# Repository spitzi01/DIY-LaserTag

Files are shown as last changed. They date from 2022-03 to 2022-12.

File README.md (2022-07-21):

# ESP32-LaserTag
Easy Open Source LaserTag System
### Überblick
Ziel dieses Projektes war der Bau eines einfachen LaserTag-Systems. Es sollte schnell und mit wenig Hardware an beliebigen Orten aufbaubar sein und  und über ein Handy gesteuert werden können.

Weitere Features sind:

- Soundausgabe für Schuss, Treffer und Nachladen (insgesamt 5 Verschiedene)
- Display in jedem Tagger
- lange Akkulaufzeit des gesamten Systems
- 3 Spielmodi
- Taschenlampe
- rote Laserdiode für Schuss-Simulation
- 5 in den Tagger integriete Infrarot-Empfänger
    
Das LaserTag-System besteht aus zwei elementaren Bestandteilen. Die Basisstation dient als Verbindungsglied zwischen den Taggern, der einzelnen Spieler, und einer HTTP-Website, welche der Konfiguration und Auswertung dient. Der Datenaustausch mit den Spielern erfolgt drahtlos mit Hilfe des EspNow-Protokolls der ESP32 S2 Mikrocontroller. Zum Spielen sind zwischen 2 und 10 Tagger notwendig. Für den Capture the Flag Spielmodus werden zusätzlich noch Flags benötigt, die die Basis und Spawnpunkt eines Team markieren.

### Basisstation
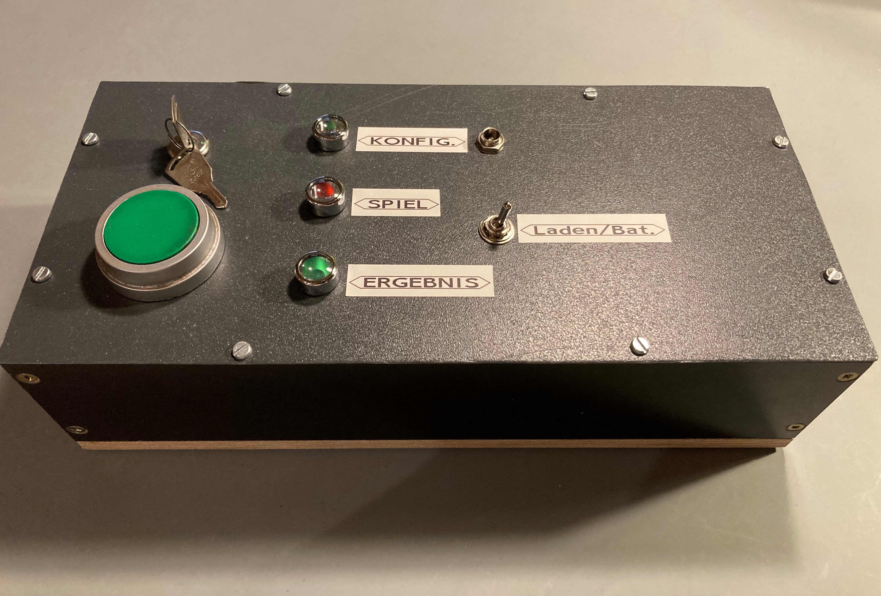
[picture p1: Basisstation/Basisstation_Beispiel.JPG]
Basisstation

Nach dem Einschalten der Basisstation wird ein WLAN-Netzwerk erzeugt und die Konfigurationswebsite gehostet. Wenn man sich hier mit einem Smartphone einloggt, kann man die Anzahl der Spieler, Dauer des Spiels, Modus, Namen der Spieler und Teamzugehörigkeit einstellen. Die maximal 10 Spieler können auf 6 Teams verteilt werden. Vor dem Starten des Spiels mit dem Start-Taster müssen unbedingt alle Tagger, die verwendet werden sollen, eingeschaltet werden, damit diese von der Basisstation ihre Informationen erhalten können. Nach Ablauf der Spieldauer übermitteln die Tagger automatisch die Spielstände an die Basisstation und schalten sich ab. Die Basisstation berechnet die Ergebnisse und hostet diese in Form einer Website. Das hat den Vorteil, dass sich theoretisch mehrere Spieler die Ergebnisse auf ihren Smartphones anschauen können.

### Tagger
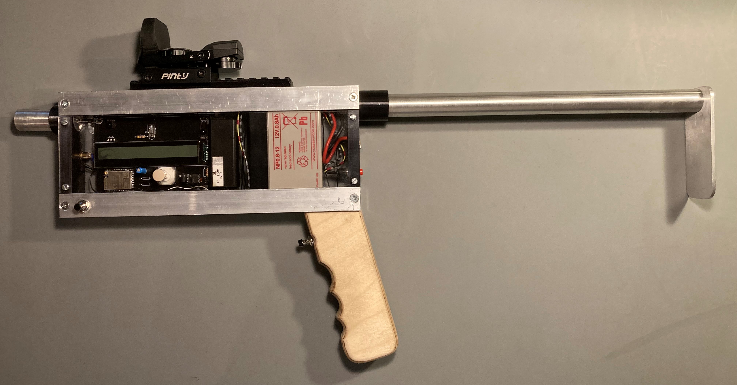
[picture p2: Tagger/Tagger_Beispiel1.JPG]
Tagger1

Bei einem Testsystem wurde festgestellt, dass es dem Spieler nicht möglich sein darf, seinen Tagger aus Versehen auszuschalten. Deshalb wird die Schaltung durch einen Taster aktiviert und nur durch den Mikrocontroller wieder deaktiviert. Außerdem soll der Spieler immer beide Hände am Tagger haben. So soll verhindert werden, dass man mit einer Hand Sensoren abdecken könnte. Dies wird durch einen Taster in Reihe zum eigentlichen Abzug realisiert. Gleichzeitig schaltet dieser auch die Taschenlampe an. In meinem Fall dient ein kleiner 12V Bleiakku aus einer Brandmeldezentrale als Energieversorgung. Mit Hilfe des Step Down Converters wird eine hohe Effizienz und Akkulaufzeit erreicht. Das Display hat 20 alphanumerische Stellen, welche die Namen der Spieler und die Anzahl der Leben anzeigen. Eine Hintergrundbeleuchtung ist nicht vorhanden, da diese zu viel Strom benötigen würde. Deshalb dient die RGB-LED für die Teamzugehörigkeit als Beleuchtung.

Tagger2

Der Schuss wird durch eine Laserdiode visualisiert. Die eigentliche Information findet durch eine IR-Übertragung ihren Weg zu anderen Spielern. Bei Tests in der Nacht konnte eine Reichweite von bis zu 60 Meter erzielt werden. Der kurze Alu-Lauf dient als Reflektor für die Infrarot-LED und auch als Kühlkörper, da bei aktiviertem Schnellfeuermodus die LED sehr belastet wird.

Die verfügbaren Spielmodi sind:

- Standard (Spielen in Teams oder Einzeln, Reaktivierung nach ca. 20 Sekunden)
- Battle Royal (Spielen in Teams oder Einzeln, Leben werden bei Treffer weniger, kein Treffer in gewisser Zeit fügt ein Leben hinzu, lange Reaktivierungszeit ca. 2 Minuten)
- Capture the Flag (2 Teams rot & blau, Flags markieren Basis oder Spawnpunkt des jeweiligen Teams, Reaktivierung nur im Bereich des eigenen Spawnpunkts, Punkte bei Aufenthalt in gegnerischen Basis)

### Flag
Ein Flag sendet in regelmäßigen Abständen einen Code der von den Taggern empfangen wird. Bereich, in dem das Signal empfangbar ist, beträgt in etwa 5-8 Meter im Radius. Diese Strecke ergibt sich durch den Einsatz von ESP32 S2 Mikrocontroller ohne integriete Antenne in den Taggern.

### Verbesserungsmöglichkeiten

- Reichweite bei starkem Sonnenschein eingeschränkt
- Mikrocontroller überträgt kurzes Störgeräusch über I2S nach Ende einer Soundausgabe (Software Problem)
- Skalierbarkeit (mehr als 10 Spieler)

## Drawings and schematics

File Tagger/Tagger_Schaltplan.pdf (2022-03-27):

GND¹⁰k +3V³ ⁺³V³ | +3V³ | 31DQ⁰⁶
3,3 | 10k 10k

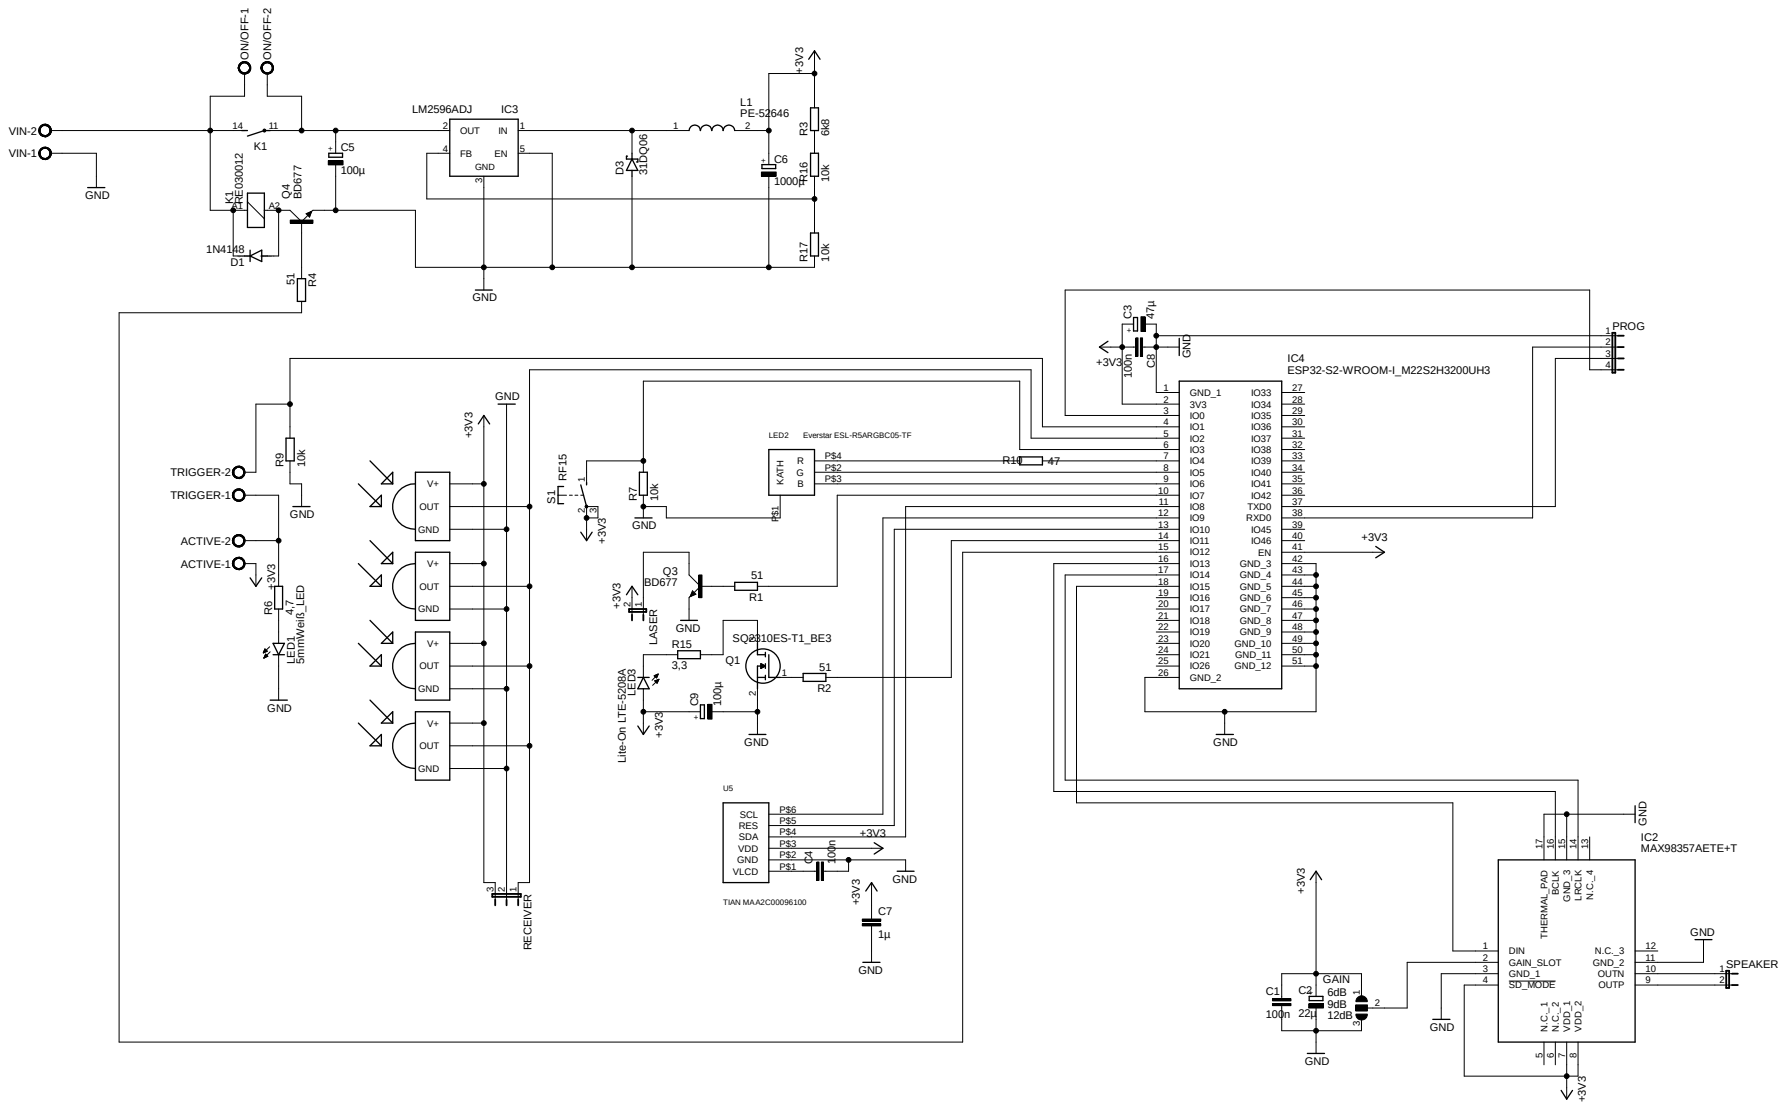
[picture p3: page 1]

GAIN ³²¹ RECEIVER Q⁴

IO10 13
IO11 14

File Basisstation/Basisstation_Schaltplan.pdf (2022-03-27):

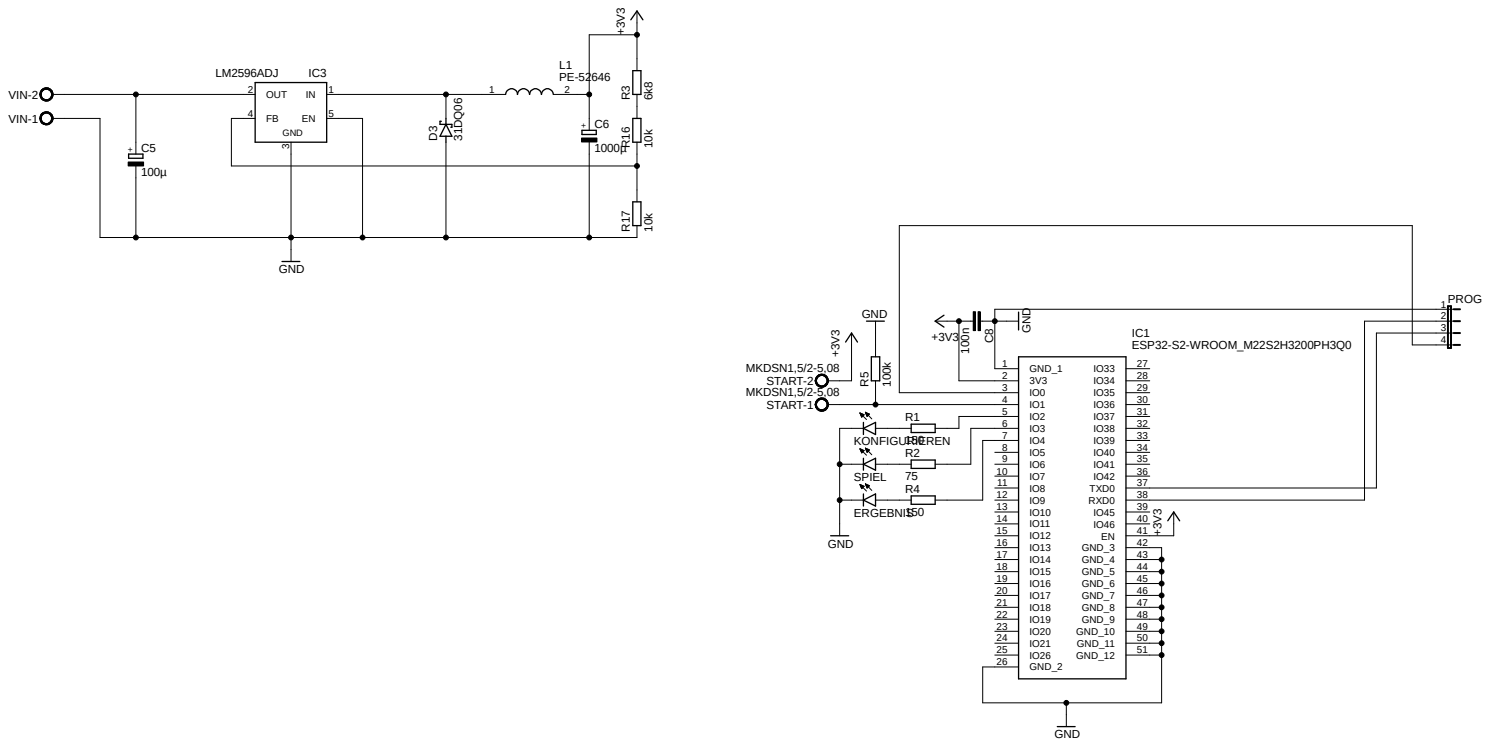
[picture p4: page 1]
GND; GND 100n; +3V3 ⁺³V³ 31DQ⁰⁶; PE-52646 LM2596ADJ; ESP32-S2-WROOM_M22S2H3200PH3Q0 +3V³; MKDSN1,5/2-5,08; MKDSN1,5/2-5,08⁺³V³; 150 ¹⁰⁰k; R¹⁶ R¹⁷; 1 OUT; 5 IC3 VIN-1 VIN-2; GND_1; 9 IO7 10 IO8 11 IO9 12 IO10 13 IO11 14 IO12 15 IO13 16 IO14 17 IO15 18 IO16 19 IO17 20 IO18 21 IO19 22 IO20 23 IO21 24 IO26 25 GND_2 26; TXD0; RXD0; GND_3; GND_4; GND_5; GND_6; GND_7; GND_8; GND_9; GND_10; GND_11; GND_12; 1234PROG; START-1; START-2; ERGEBNIS; SPIEL; KONFIGURIEREN ⁺

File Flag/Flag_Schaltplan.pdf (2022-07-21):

# D2 ¹²³ON/OFF

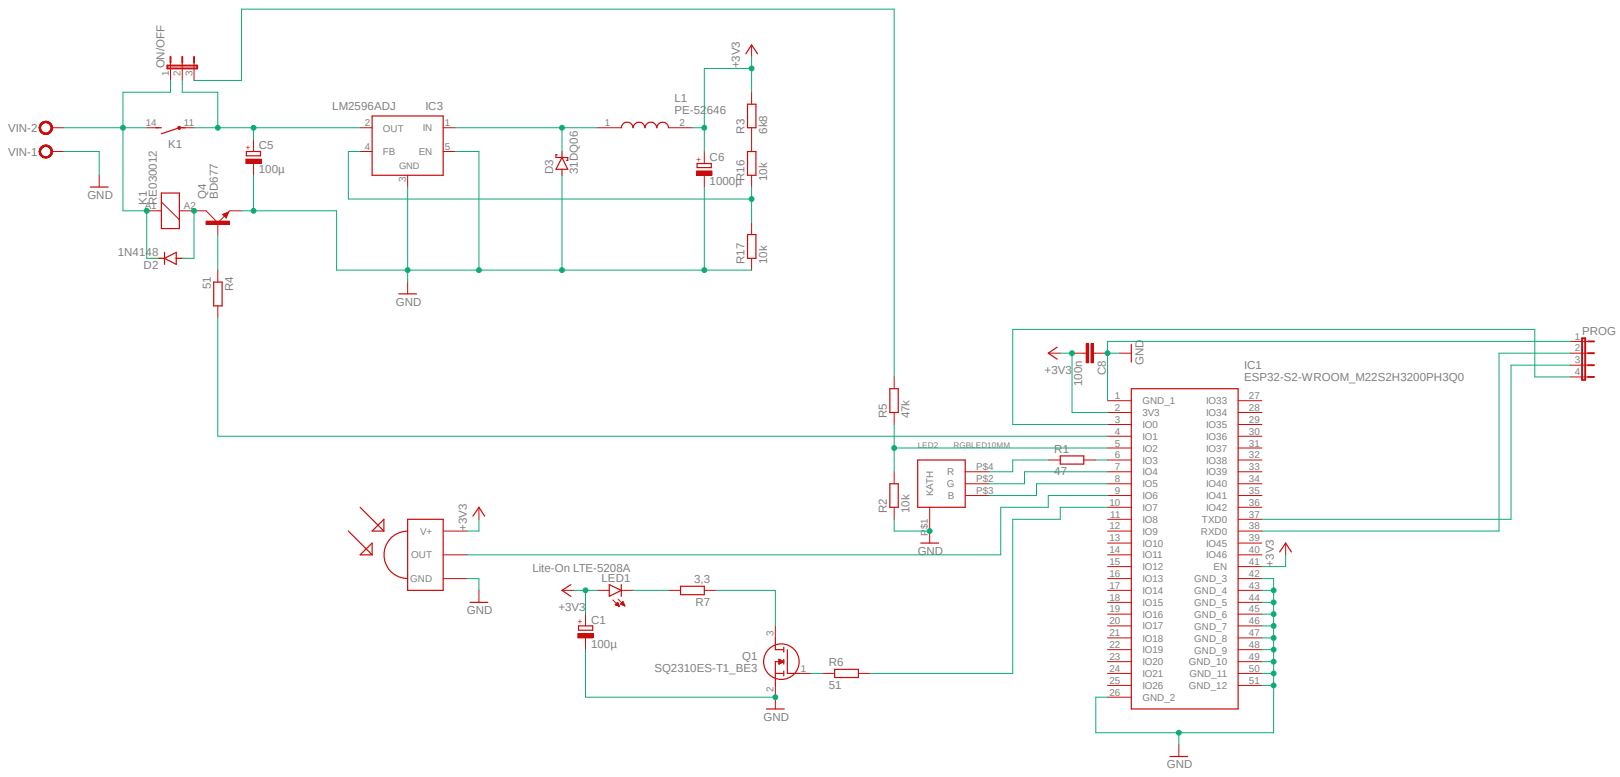
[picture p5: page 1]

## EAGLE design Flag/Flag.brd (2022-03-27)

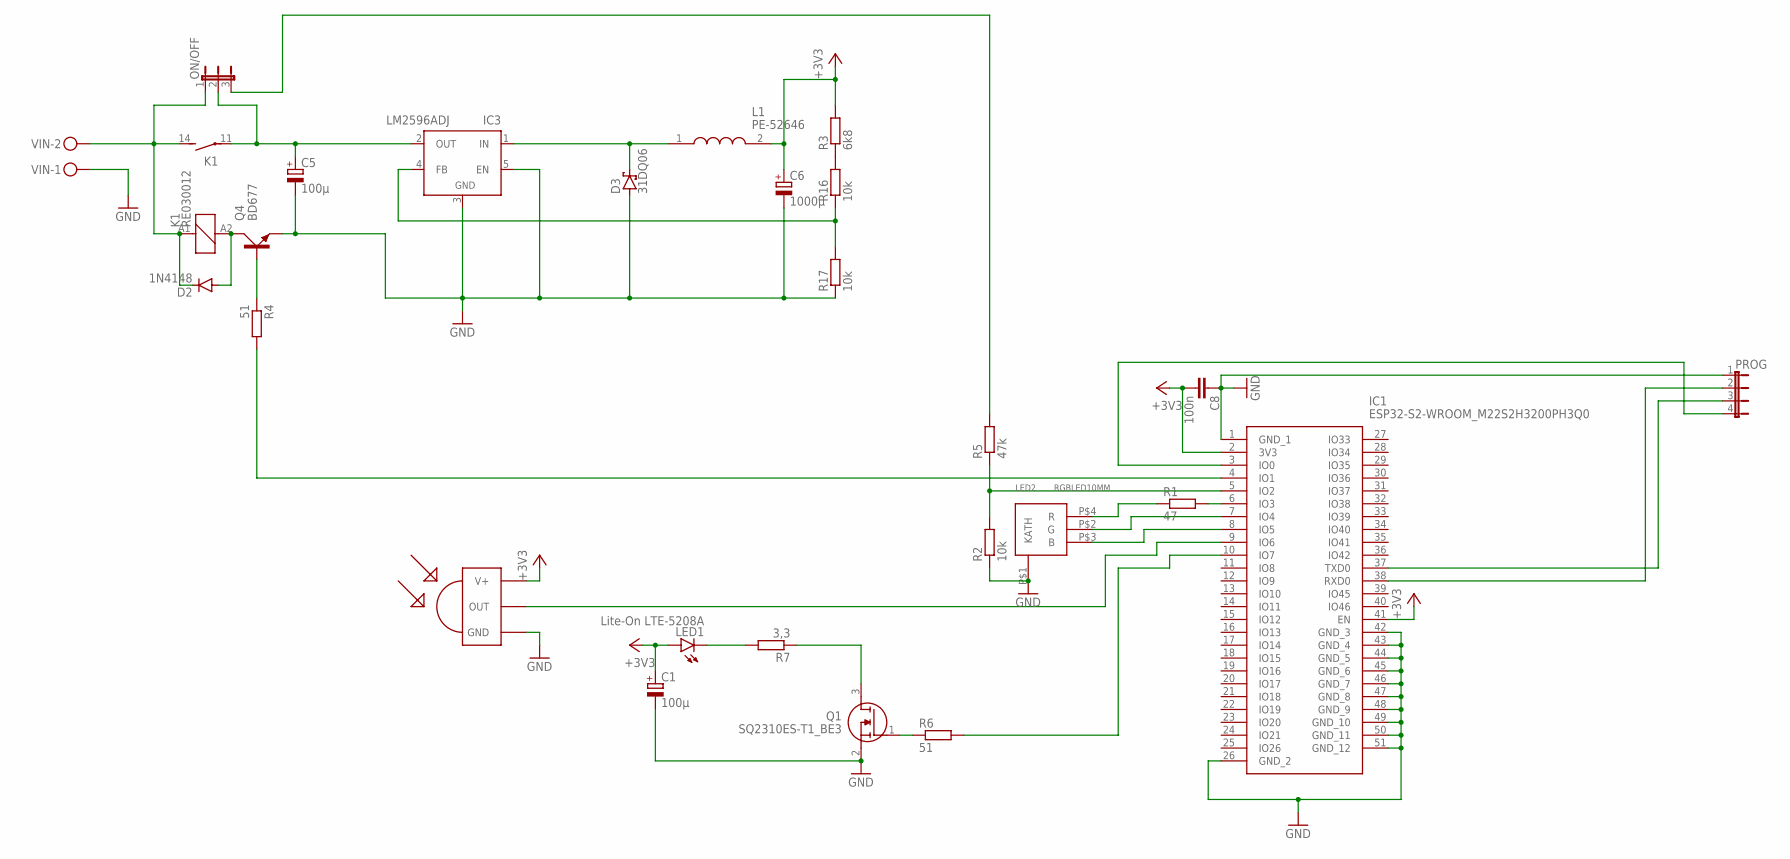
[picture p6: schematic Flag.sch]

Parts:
C1: 100µ; E3,5-8
C5: 100µ; E5-10,5
C6: 1000µ; E3,5-8
C8: 100n; C050-025X075
D2: 1N4148; SOD80C
D3: 31DQ06; C4111-15
IC1: ESP32-S2-WROOM_M22S2H3200PH3Q0; ESP32S2WROOMM22S2H3200PH3Q0
IC3: LM2596ADJ; TO220-52
K1: RE030012; RE-SCHRACK
L1: PE-52646; PE52646
LED1: Lite-On LTE-5208A; LED5MM
LED2: RGBLED10MM
ON/OFF: JP2E; JP2
PROG: JP4E; JP4
Q1: SQ2310ES-T1_BE3; SOT95P237X112-3N
Q4: BD677; TO126AV
R1: 47; 0207/10
R2: 10k; 0207/10
R3: 6k8; R1206
R4, R6: 51; R1206
R5: 47k; 0207/10
R7: 3,3; 0207/10
R16, R17: 10k; R1206
U1: TSOP33338; TSOP18XX
VIN: MKDSN1,5/2-5,08

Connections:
+3V3: C1.+, C6.+, C8.2, IC1.2 (3V3), IC1.41 (EN), L1.2, LED1.A, R3.2, U1.VCC (V+)
GND: C1.-, C5.-, C6.-, C8.1, D3.A, IC1.1 (GND_1), IC1.26 (GND_2), IC1.42 (GND_3), IC1.43 (GND_4), IC1.44 (GND_5), IC1.45 (GND_6), IC1.46 (GND_7), IC1.47 (GND_8), IC1.48 (GND_9), IC1.49 (GND_10), IC1.50 (GND_11), IC1.51 (GND_12), IC3.3 (GND), IC3.5 (EN), LED2.P$1 (KATH), PROG.1, Q1.2 (S), Q4.E, R2.1, R17.1, U1.GND, VIN.1
unnamed: C5.+, IC3.2 (OUT), K1.11, ON/OFF.2
unnamed: IC1.4 (IO1), R4.2
unnamed: D2.C, K1.14 (S), K1.A1 (1), ON/OFF.1, VIN.2
unnamed: D2.A, K1.A2 (2), Q4.C
unnamed: LED2.P$4 (R), R1.1
unnamed: IC1.7 (IO4), LED2.P$2 (G)
unnamed: IC1.8 (IO5), LED2.P$3 (B)
unnamed: D3.C, IC3.1 (IN), L1.1
unnamed: IC3.4 (FB), R16.1, R17.2
unnamed: IC1.6 (IO3), R1.2
unnamed: IC1.5 (IO2), R2.2, R5.1
unnamed: IC1.9 (IO6), U1.OUT
unnamed: ON/OFF.3, R5.2
unnamed: IC1.10 (IO7), R6.2
unnamed: Q1.1 (G), R6.1
unnamed: LED1.K (C), R7.2
unnamed: Q1.3 (D), R7.1
unnamed: Q4.B, R4.1
unnamed: IC1.3 (IO0), PROG.4
unnamed: IC1.37 (TXD0), PROG.3
unnamed: IC1.38 (RXD0), PROG.2
unnamed: R3.1, R16.2

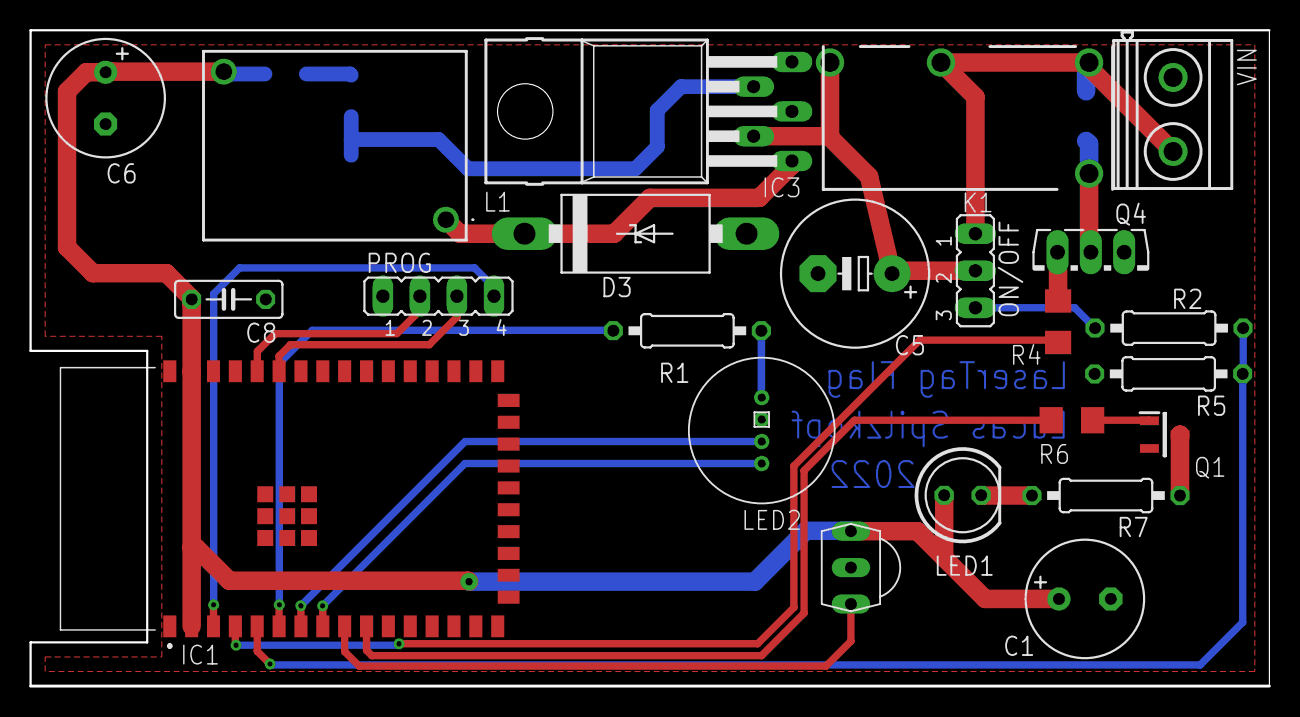
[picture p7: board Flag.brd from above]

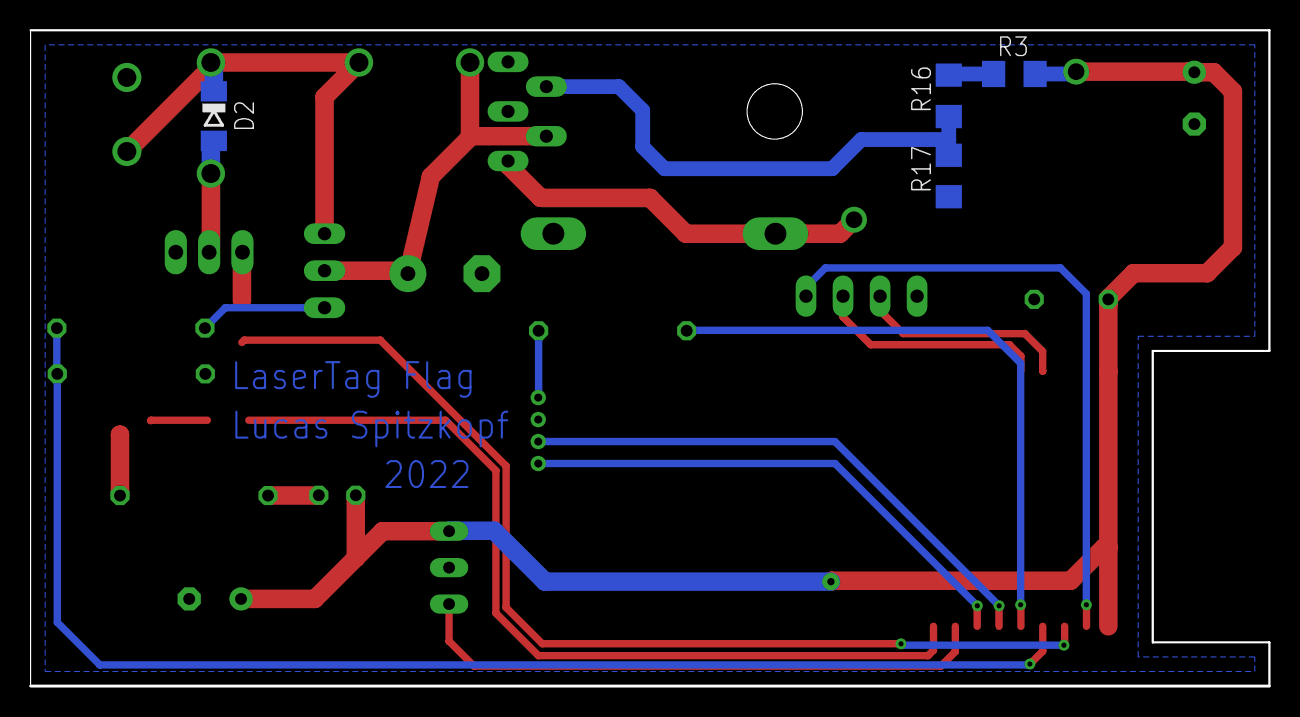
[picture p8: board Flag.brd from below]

Board: 2 copper layers, 85.0 x 45.0 mm, 27 parts (4 on the bottom side), 24 nets.

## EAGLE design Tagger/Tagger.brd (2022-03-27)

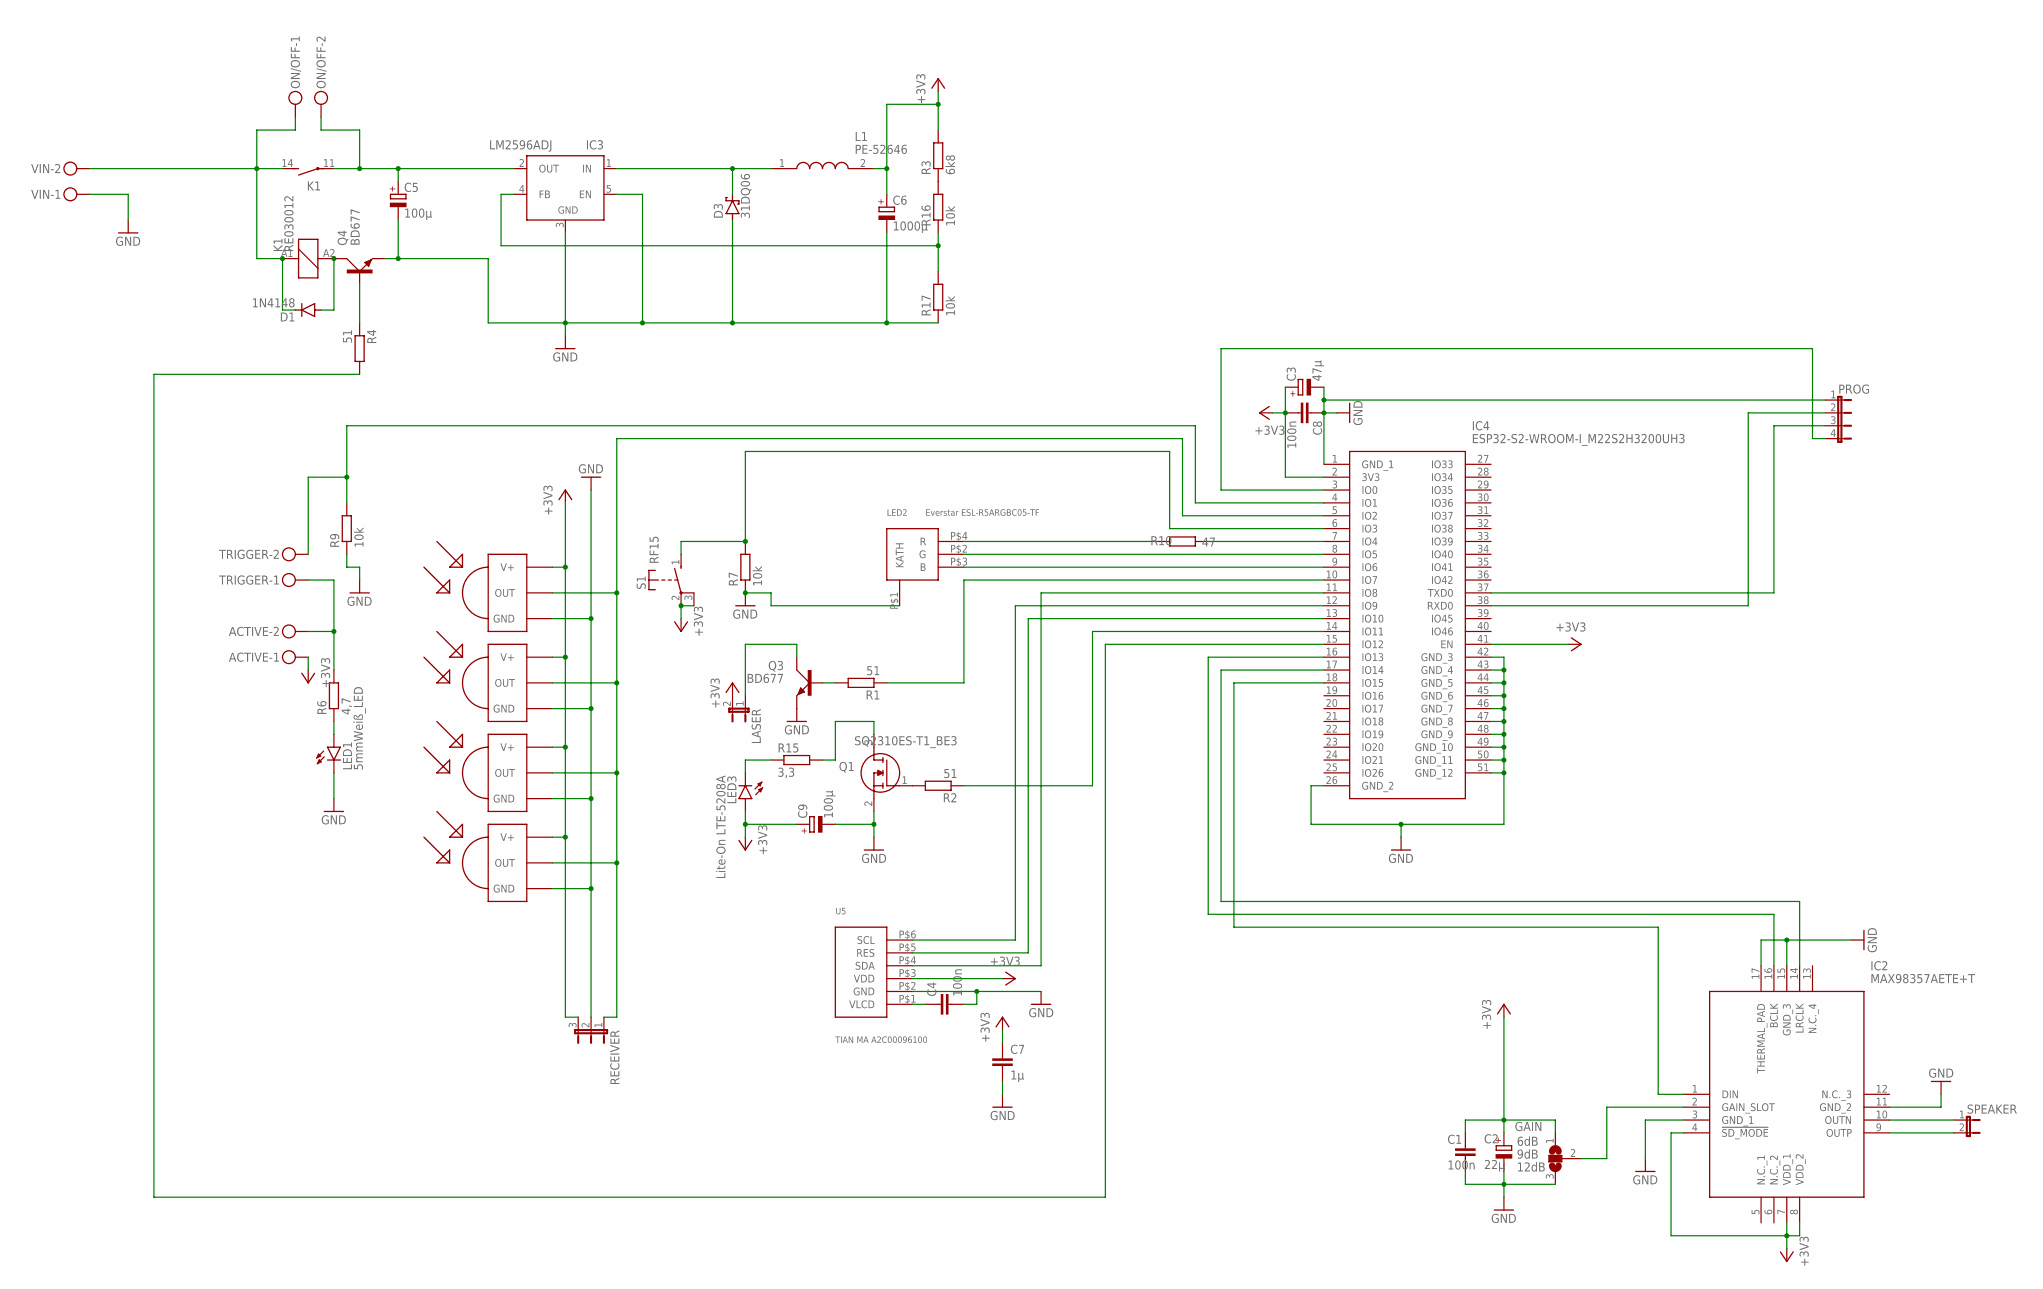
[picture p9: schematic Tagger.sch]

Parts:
ACTIVE: MKDSN1,5/2-5,08
C1, C4, C8: 100n; C1206
C2: 22µ; E2-5
C3: 47µ; E2-5
C5: 100µ; E2,5-6E
C6: 1000µ; E5-10,5
C7: 1µ; C0805
C9: 100µ; E2,5-6
D1: 1N4148; SOD80C
D3: 31DQ06; C4111-15
GAIN: SJ2WW; SJ_2W
IC2: MAX98357AETE+T; QFN50P300X300X80-17N
IC3: LM2596ADJ; TO220-52
IC4: ESP32-S2-WROOM-I_M22S2H3200UH3; ESP32S2WROOMIM22S2H3200UH3Q0
K1: RE030012; RE-SCHRACK
L1: PE-52646; PE52646
LASER: JP1E; JP1
LED1: 5mmWeiß_LED; LED5MM
LED2: Everstar ESL-R5ARGBC05-TF; RGBLED5MM
LED3: Lite-On LTE-5208A; LED5MM
ON/OFF: MKDSN1,5/2-5,08
PROG: JP4E; JP4
Q1: SQ2310ES-T1_BE3; SOT95P237X112-3N
Q3, Q4: BD677; TO126AV
R1, R2, R4: 51; R1206
R3: 6k8; R1206
R6: 4,7; 0207/10
R7, R9, R16, R17: 10k; R1206
R10: 47; 0207/10
R15: 3,3; 0207/10
RECEIVER: JP2E; JP2
S1: RF15
SPEAKER: JP1E; JP1
TRIGGER: MKDSN1,5/2-5,08
U1, U2, U3, U4: TSOP33338; TSOP18XX
U5: TIAN MA A2C00096100; LCD_DISPLAY
VIN: MKDSN1,5/2-5,08

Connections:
+3V3: ACTIVE.1, C1.1, C2.+, C3.+, C6.+, C7.1, C8.2, C9.+, GAIN.1, IC2.4 (!SD_MODE), IC2.7 (VDD_1), IC2.8 (VDD_2), IC4.2 (3V3), IC4.41 (EN), L1.2, LASER.2, LED3.A, R3.2, RECEIVER.3, S1.2, S1.3, U1.VCC (V+), U2.VCC (V+), U3.VCC (V+), U4.VCC (V+), U5.P$3 (VDD)
GND: C1.2, C2.-, C3.-, C4.2, C5.-, C6.-, C7.2, C8.1, C9.-, D3.A, GAIN.3, IC2.3 (GND_1), IC2.11 (GND_2), IC2.15 (GND_3), IC2.17 (THERMAL_PAD), IC3.3 (GND), IC3.5 (EN), IC4.1 (GND_1), IC4.26 (GND_2), IC4.42 (GND_3), IC4.43 (GND_4), IC4.44 (GND_5), IC4.45 (GND_6), IC4.46 (GND_7), IC4.47 (GND_8), IC4.48 (GND_9), IC4.49 (GND_10), IC4.50 (GND_11), IC4.51 (GND_12), LED1.K (C), LED2.P$1 (KATH), PROG.1, Q1.2 (S), Q3.E, Q4.E, R7.1, R9.1, R17.1, RECEIVER.2, U1.GND, U2.GND, U3.GND, U4.GND, U5.P$2 (GND), VIN.1
unnamed: C5.+, IC3.2 (OUT), K1.11, ON/OFF.2
unnamed: GAIN.2, IC2.2 (GAIN_SLOT)
unnamed: D1.C, K1.14 (S), K1.A1 (1), ON/OFF.1, VIN.2
unnamed: D1.A, K1.A2 (2), Q4.C
unnamed: IC4.7 (IO4), R10.2
unnamed: IC2.10 (OUTN), SPEAKER.1
unnamed: IC2.1 (DIN), IC4.18 (IO15)
unnamed: C4.1, U5.P$1 (VLCD)
unnamed: D3.C, IC3.1 (IN), L1.1
unnamed: IC3.4 (FB), R16.1, R17.2
unnamed: IC2.14 (LRCLK), IC4.17 (IO14)
unnamed: IC4.14 (IO11), R2.1
unnamed: LED3.K (C), R15.1
unnamed: LASER.1, Q3.C
unnamed: LED1.A, R6.1
unnamed: IC4.11 (IO8), U5.P$4 (SDA)
unnamed: Q1.3 (D), R15.2
unnamed: IC4.6 (IO3), R7.2, S1.1 (S)
unnamed: Q4.B, R4.1
unnamed: LED2.P$4 (R), R10.1
unnamed: IC4.8 (IO5), LED2.P$2 (G)
unnamed: IC4.9 (IO6), LED2.P$3 (B)
unnamed: IC2.16 (BCLK), IC4.16 (IO13)
unnamed: IC4.4 (IO1), R9.2, TRIGGER.2
unnamed: IC4.10 (IO7), R1.1
unnamed: Q3.B, R1.2
unnamed: IC4.13 (IO10), U5.P$5 (RES)
unnamed: IC4.12 (IO9), U5.P$6 (SCL)
unnamed: IC2.9 (OUTP), SPEAKER.2
unnamed: IC4.3 (IO0), PROG.4
unnamed: Q1.1 (G), R2.2
unnamed: IC4.5 (IO2), RECEIVER.1, U1.OUT, U2.OUT, U3.OUT, U4.OUT
unnamed: IC4.37 (TXD0), PROG.3
unnamed: IC4.38 (RXD0), PROG.2
unnamed: ACTIVE.2, R6.2, TRIGGER.1
unnamed: R3.1, R16.2
unnamed: IC4.15 (IO12), R4.2

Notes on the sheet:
12dB
9dB
6dB

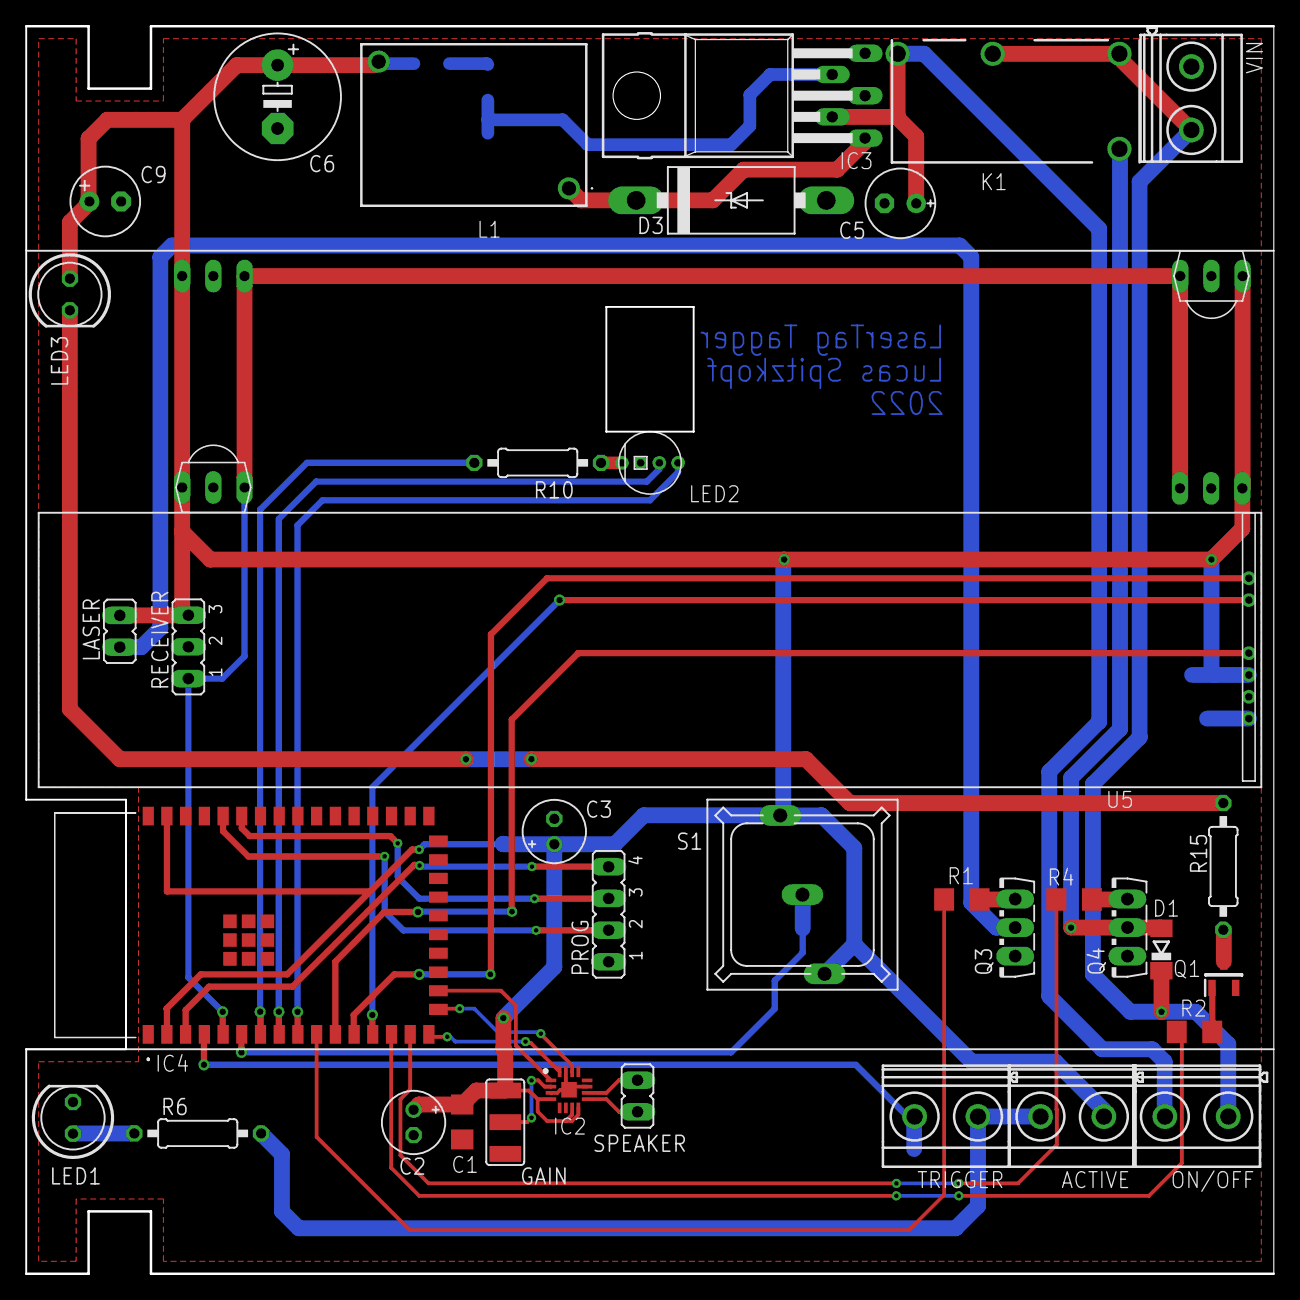
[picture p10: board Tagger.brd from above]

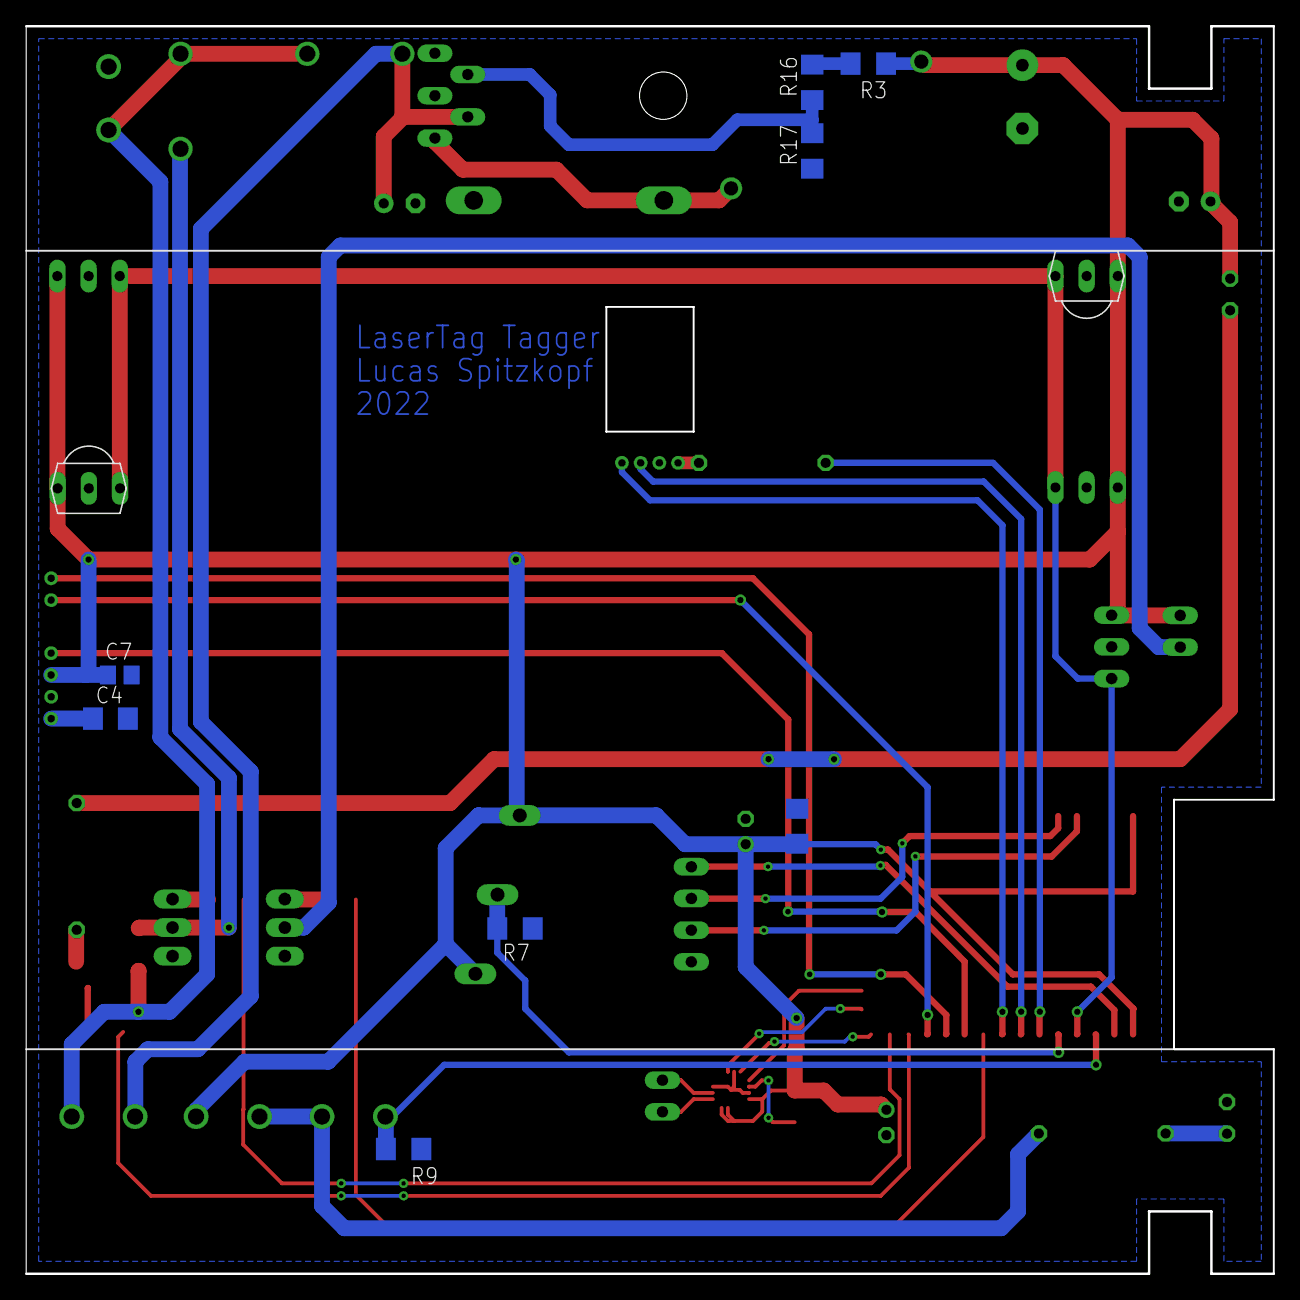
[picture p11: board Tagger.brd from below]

Board: 2 copper layers, 100.0 x 100.0 mm, 48 parts (10 on the bottom side), 39 nets.

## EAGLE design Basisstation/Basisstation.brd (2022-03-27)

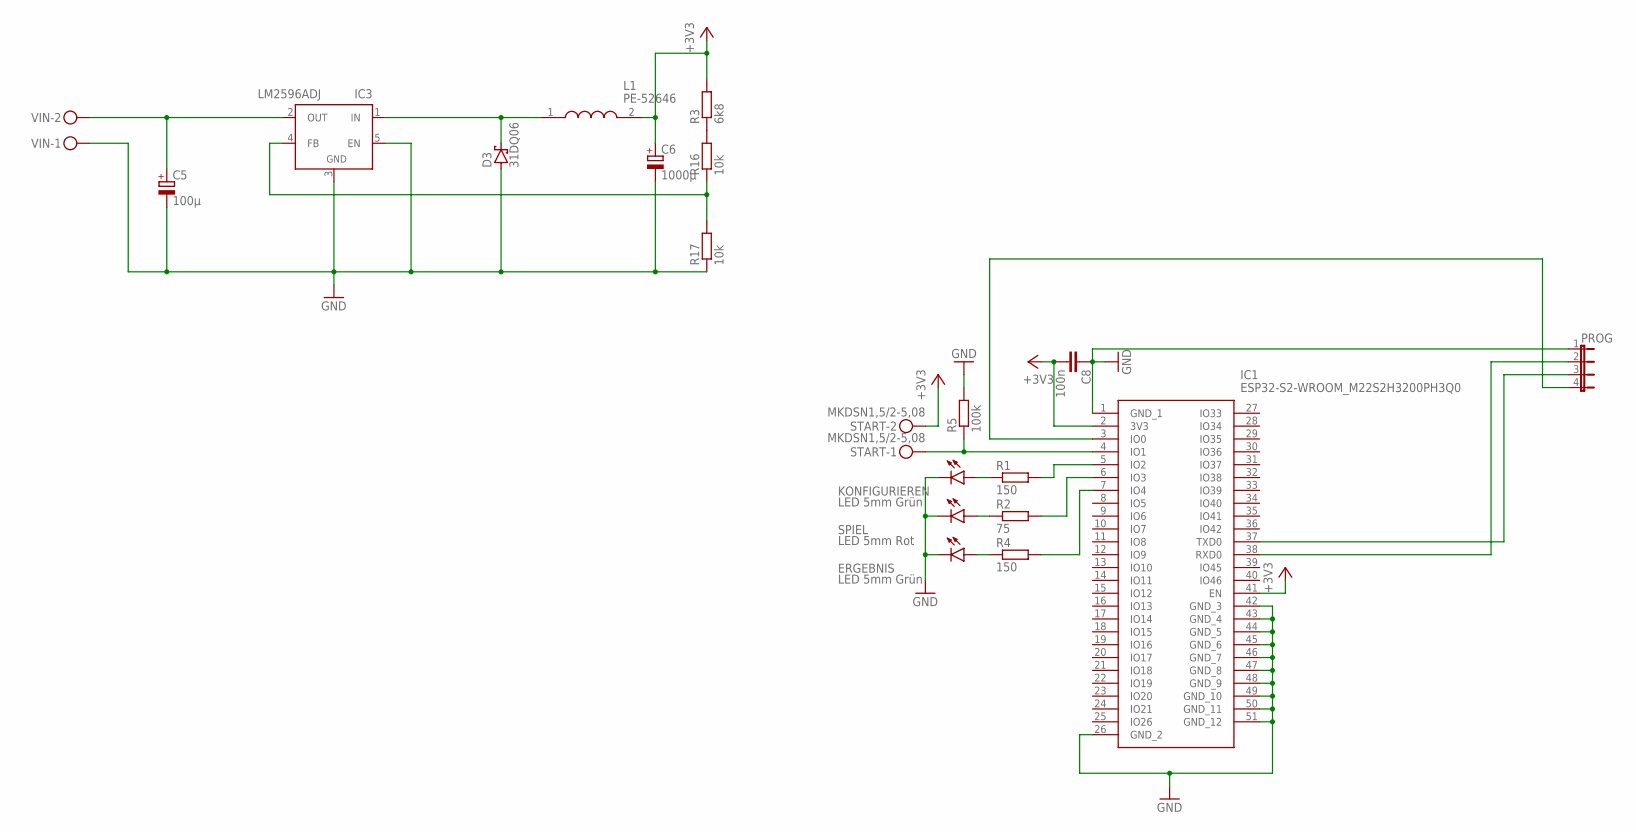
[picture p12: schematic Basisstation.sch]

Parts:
C5: 100µ; E5-10,5
C6: 1000µ; E3,5-8
C8: 100n; C050-025X075
D3: 31DQ06; C4111-15
ERGEBNIS: LED 5mm Grün; LED5MM
IC1: ESP32-S2-WROOM_M22S2H3200PH3Q0; ESP32S2WROOMM22S2H3200PH3Q0
IC3: LM2596ADJ; TO220-52
KONFIGURIEREN: LED 5mm Grün; LED5MM
L1: PE-52646; PE52646
PROG: JP4E; JP4
R1, R4: 150; 0207/10
R2: 75; 0207/10
R3: 6k8; R1206
R5: 100k; 0207/10
R16, R17: 10k; R1206
SPIEL: LED 5mm Rot; LED5MM
START: MKDSN1,5/2-5,08
VIN: MKDSN1,5/2-5,08

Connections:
+3V3: C6.+, C8.2, IC1.2 (3V3), IC1.41 (EN), L1.2, R3.2, START.2
GND: C5.-, C6.-, C8.1, D3.A, ERGEBNIS.K (C), IC1.1 (GND_1), IC1.26 (GND_2), IC1.42 (GND_3), IC1.43 (GND_4), IC1.44 (GND_5), IC1.45 (GND_6), IC1.46 (GND_7), IC1.47 (GND_8), IC1.48 (GND_9), IC1.49 (GND_10), IC1.50 (GND_11), IC1.51 (GND_12), IC3.3 (GND), IC3.5 (EN), KONFIGURIEREN.K (C), PROG.1, R5.2, R17.1, SPIEL.K (C), VIN.1
unnamed: IC1.5 (IO2), R1.2
unnamed: IC1.4 (IO1), R5.1, START.1
unnamed: C5.+, IC3.2 (OUT), VIN.2
unnamed: KONFIGURIEREN.A, R1.1
unnamed: R2.1, SPIEL.A
unnamed: ERGEBNIS.A, R4.1
unnamed: IC1.6 (IO3), R2.2
unnamed: IC1.7 (IO4), R4.2
unnamed: D3.C, IC3.1 (IN), L1.1
unnamed: IC3.4 (FB), R16.1, R17.2
unnamed: IC1.3 (IO0), PROG.4
unnamed: IC1.37 (TXD0), PROG.3
unnamed: IC1.38 (RXD0), PROG.2
unnamed: R3.1, R16.2

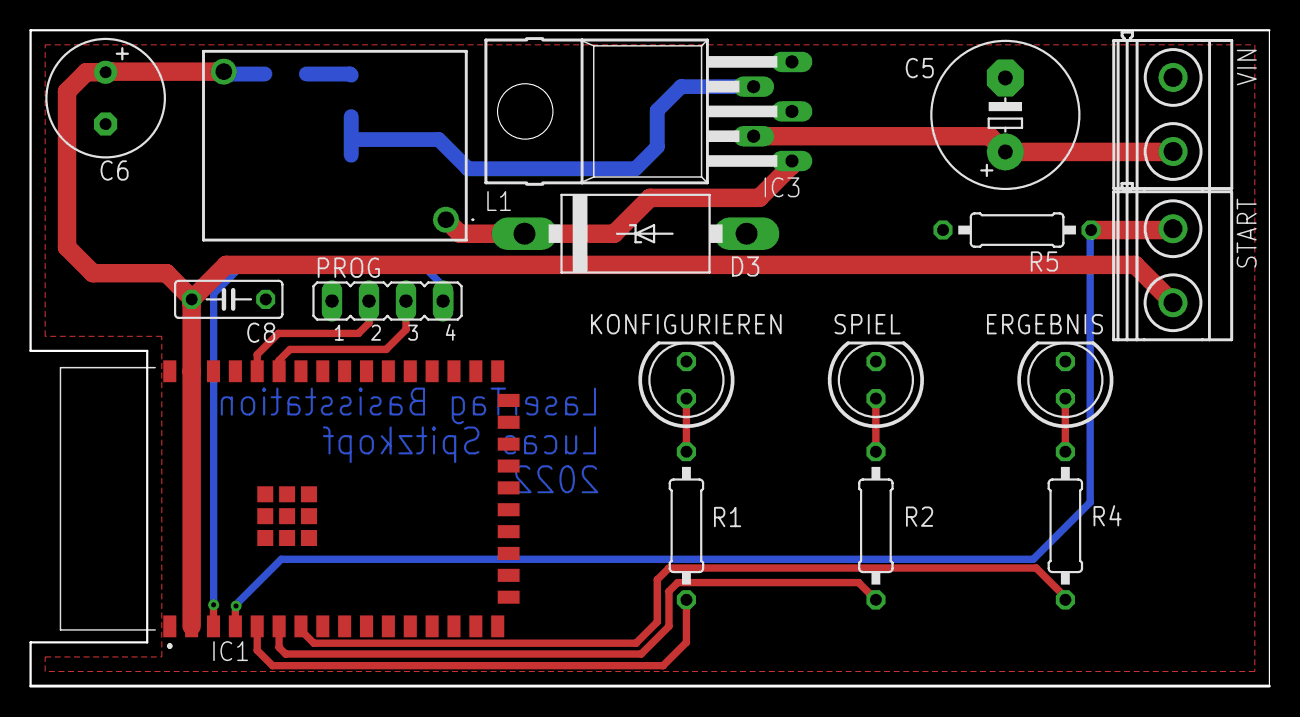
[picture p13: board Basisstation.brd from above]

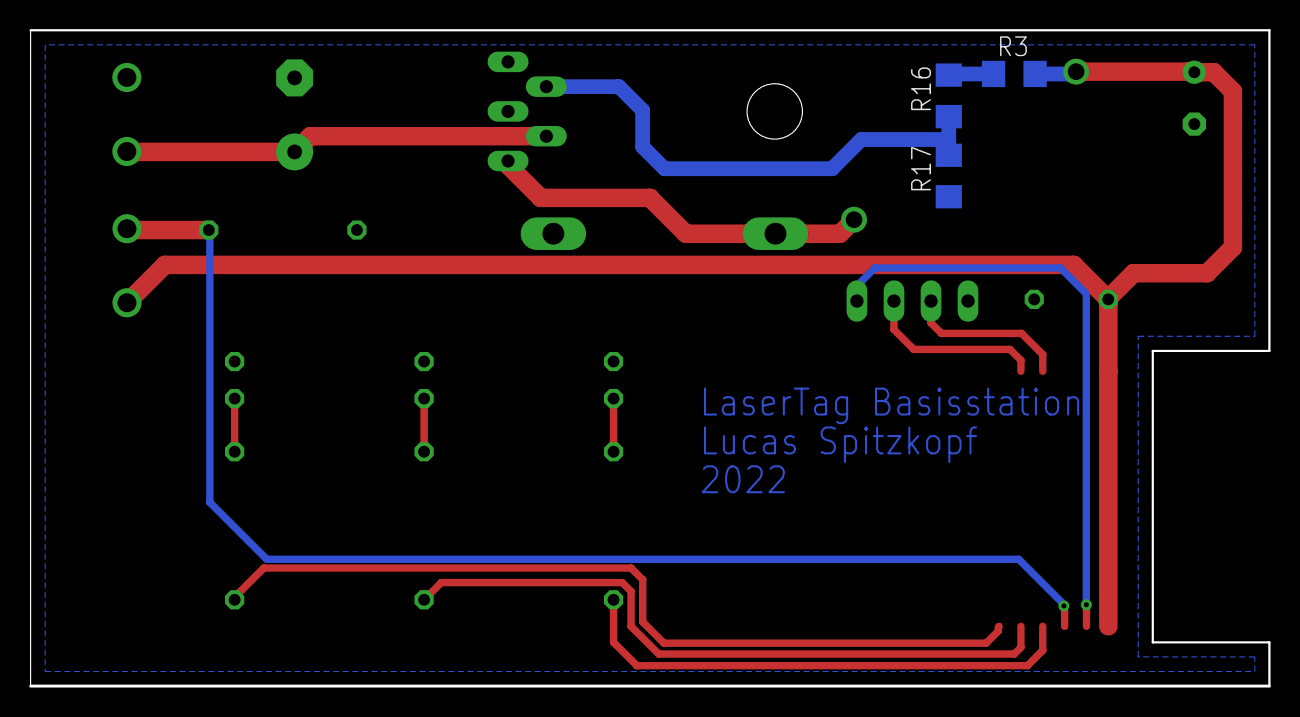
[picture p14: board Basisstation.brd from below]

Board: 2 copper layers, 85.0 x 45.0 mm, 20 parts (3 on the bottom side), 16 nets.

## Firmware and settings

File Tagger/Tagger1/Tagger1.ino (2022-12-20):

#include "driver/i2s.h"
#include "WavData.h"
#include "data.h"
#include "PCF2119.h"
#include "ESP32_New_TimerInterrupt.h"
#include <esp_now.h>
#include <WiFi.h>

// Pin-Definitionen \\

#define Trigger_Pin 1
#define Receiver_Pin 2
#define Menue_Pin 3
#define R_Led_Pin 4
#define G_Led_Pin 5
#define B_Led_Pin 6
#define Laser_Pin 7
#define Display_SDA 8
#define Display_SCL 9
#define Display_Reset 10
#define IR_Pin 11
#define Enable_Pin 12
#define I2S_BCLK_Pin 13
#define I2S_LRCL_Pin 14
#define I2S_DOUT_Pin 15

// I2S-Audio Definition \\

static const i2s_port_t i2s_num = I2S_NUM_0;  // I2S Port Nummer
unsigned const char* TheData1;                // Schuss-Sound
unsigned const char* TheData2;                // Schnellfeuer-Sound
unsigned const char* TheData3;                // Damage-Sound
unsigned const char* TheData4;                // Magazin-Leer-Sound
unsigned const char* TheData5;                // Magazin-Laden-Sound
uint32_t DataIdx=0;                           // Offset in TheData

struct WavHeader_Struct
{
  //   RIFF Section    
  char RIFFSectionID[4];          // Letters "RIFF"
  uint32_t Size;                  // Size of entire file less 8
  char RiffFormat[4];             // Letters "WAVE"
      
  //   Format Section    
  char FormatSectionID[4];        // letters "fmt"
  uint32_t FormatSize;            // Size of format section less 8
  uint16_t FormatID;              // 1=uncompressed PCM
  uint16_t NumChannels;           // 1=mono,2=stereo
  uint32_t SampleRate;            // 44100, 16000, 8000 etc.
  uint32_t ByteRate;              // =SampleRate * Channels * (BitsPerSample/8)
  uint16_t BlockAlign;            // =Channels * (BitsPerSample/8)
  uint16_t BitsPerSample;         // 8,16,24 or 32
   
  // Data Section
  char DataSectionID[4];          // The letters "data"
  uint32_t DataSize;              // Size of the data that follows
}WavHeader1, WavHeader2, WavHeader3, WavHeader4, WavHeader5;
    
static const i2s_config_t i2s_config = {
    .mode = (i2s_mode_t)(I2S_MODE_MASTER | I2S_MODE_TX),
    .sample_rate = 44100,                                         // Note, this will be changed later
    .bits_per_sample = I2S_BITS_PER_SAMPLE_16BIT,
    .channel_format = I2S_CHANNEL_FMT_RIGHT_LEFT,
    .communication_format = (i2s_comm_format_t)(I2S_COMM_FORMAT_I2S | I2S_COMM_FORMAT_I2S_MSB),
    .intr_alloc_flags = ESP_INTR_FLAG_LEVEL1,                     // hohe Interrupt-Priorität
    .dma_buf_count = 8,                                           // 8 Puffer-Speicher
    .dma_buf_len = 1024,                                          // 1K pro Puffer -> 8k 
    .use_apll=0,
    .tx_desc_auto_clear= true, 
    .fixed_mclk=-1    
};

static const i2s_pin_config_t pin_config = {
    .bck_io_num = 13,                                   // Pin für Bit-Clock
    .ws_io_num = 14,                                    // Pin für Word Select
    .data_out_num = 15,                                 // Pin für Data Out
    .data_in_num = I2S_PIN_NO_CHANGE                    // I2S Eingang -> Uninteressant
};

// Display-Definition \\

pcf2119 display = pcf2119(Display_Reset);               // Erzeugung des Display-Objektes

// Globale Variablen \\

Daten x;                                                // Struktur für alle Spiel-relevanten Daten
int Status = LOW, Status_alt = LOW;                     // Zustandsvariablen für Trigger
uint8_t Magazin;                                        // Anzahl der Schüsse im Magazin
volatile uint8_t Leben;									// Anzahl der erlaubten Treffer
volatile uint8_t dauer = -1;                            // Dauer des Spiels bisher in Minuten
volatile int reload = -1;                               // Variable zur Koordination des Nachlade-Zyklus
volatile unsigned long ID[22];                          // Variable für Treffer-Identifikation
volatile int count = 0;
volatile bool change = false;
uint8_t beacon = 0;
bool success1 = false;                                  // Zustand der empfangenen Daten
bool success2 = false;
uint8_t mac0[] = {0x7C, 0xDF, 0xA1, 0x40, 0xCC, 0xD8};  // MAC-Adresse des Servers
int druck = 0;                                          // Zustandsvariable für Beenden des Spiels

// Timer und Interrupts \\

ESP32Timer ITimer0(0);                                  // Timer0 initialisieren
 
bool IRAM_ATTR TimerHandler0(void * timerNo)            // Timer-Handler für Timer0
{
  dauer++;
  return true;
}

ESP32Timer ITimer1(1);                                  // Timer1 initialisieren
 
bool IRAM_ATTR TimerHandler1(void * timerNo)            // Timer-Handler für Timer1
{
  reload++;
  return true;
}

ESP32Timer ITimer2(2);                                  // Timer2 initialisieren
 
bool IRAM_ATTR TimerHandler2(void * timerNo)            // Timer-Handler für Timer2
{
  if(Leben < x.Leben_Reload) Leben++;
  if(Leben == x.Leben_Reload) ITimer2.stopTimer();
  change = true;
  return true;
}

void IRAM_ATTR ISR()                                    // ISR-Handler für IR-Receiver
{
    if(count < 22)
    {
      ID[count] = micros();
      count++;
    }
    else
    {
      count = 0;
      detachInterrupt(Receiver_Pin);
    }
}

// Funkübertragung \\

void OnDataRecv(const uint8_t * mac, const uint8_t *incomingData, int len)        // Verarbeitung empfangener Daten
{
  if(len > 8)
  {
    memcpy(&x, incomingData, sizeof(x));
    success1 = true;
  }
  else
  {
    memcpy(&beacon, incomingData, sizeof(beacon));
    success2 = true;
  }
}

void OnDataSent(const uint8_t *mac_addr, esp_now_send_status_t status)            // Prüfung der Sendung
{
  if(status == ESP_NOW_SEND_SUCCESS) success1 = true;
  else success1 = false;
}

void setup()
{
  // Pin-Initialisierung \\

  pinMode(Trigger_Pin, INPUT);
  pinMode(Receiver_Pin, INPUT);
  pinMode(Menue_Pin, INPUT);
  pinMode(R_Led_Pin, OUTPUT);
  digitalWrite(R_Led_Pin, LOW);
  pinMode(G_Led_Pin, OUTPUT);
  digitalWrite(G_Led_Pin, LOW);
  pinMode(B_Led_Pin, OUTPUT);
  digitalWrite(B_Led_Pin, LOW);
  pinMode(Laser_Pin, OUTPUT);
  digitalWrite(Laser_Pin, LOW);
  pinMode(IR_Pin, OUTPUT);
  pinMode(Enable_Pin, OUTPUT);
  digitalWrite(Enable_Pin, HIGH);
  pinMode(I2S_BCLK_Pin, OUTPUT);
  pinMode(I2S_LRCL_Pin, OUTPUT);
  pinMode(I2S_DOUT_Pin, OUTPUT);

  // PWM-Erzeugung für IR-Sender\\

  ledcSetup(0, 38000, 8);
  ledcAttachPin(IR_Pin, 0);

  // Wav-Daten vorbereiten \\
  
  memcpy(&WavHeader1,&schuss1,44);                            // Kopiere den Haeder von schuss1 in die Struktur
  memcpy(&WavHeader2,&schuss2,44);                            // Kopiere den Haeder von schuss2 in die Struktur
  memcpy(&WavHeader3,&treffer,44);                            // Kopiere den Haeder von treffer in die Struktur
  memcpy(&WavHeader4,&leer,44);                               // Kopiere den Haeder von leer in die Struktur
  memcpy(&WavHeader5,&laden,44);                              // Kopiere den Haeder von laden in die Struktur
  i2s_driver_install(i2s_num, &i2s_config, 0, NULL);          // ESP32 stellt Ressourcen für I2S
  i2s_set_pin(i2s_num, &pin_config);                          // Pin-Zuweisung
  i2s_set_sample_rates(i2s_num, WavHeader1.SampleRate);       // Setze Samplerate
  TheData1=schuss1;                                           // Setze Anfangspunkt für schuss1
  TheData1+=44;
  TheData2=schuss2;                                           // Setze Anfangspunkt für schuss2
  TheData2+=44;
  TheData3=treffer;                                           // Setze Anfangspunkt treffer
  TheData3+=44;
  TheData4=leer;                                              // Setze Anfangspunkt leer
  TheData4+=44;
  TheData5=laden;                                             // Setze Anfangspunkt laden
  TheData5+=44;


  // Display-Initialisierung \\

  display.set_hv_pump(PCF2119_VLCD_GENERATOR_STAGES_2);       // Ladungspumpe für 3,3V VCC konfigurieren
  display.set_mux(PCF2119_MUX_1_18);
  display.init();                                             // Initialisieren des Displays

  // Block für WLAN-Verbindung
  
  WiFi.mode(WIFI_STA);                      // Wifi im Station-Mode
  esp_now_init();                           // ESP-NOW initialisieren

  esp_now_register_send_cb(OnDataSent);     // Senden aktivieren

  esp_now_peer_info_t peerInfo;             // Verbindung mit Server aufbauen
  memcpy(peerInfo.peer_addr, mac0, 6);
  peerInfo.channel = 0;  
  peerInfo.encrypt = false;
  esp_now_add_peer(&peerInfo);

  esp_now_register_recv_cb(OnDataRecv);     // Empfang aktivieren
  
  {
    int i = 0;
    while((success1 == false)&&(i < 300))
    {
      delay(100);
      i++;
    }
    if(i == 300) digitalWrite(Enable_Pin, LOW);
  }
  x.num = 0;
  Magazin = x.Magazin_Reload;
  Leben = x.Leben_Reload;
  success1 = false;

  // Anfangsprozedur für das Spiel \\

  for(int i = 30; i > 0; i--)               // Countdown auf dem Display
  {
    display.clear_screen();
    display.return_home();
    display.set_ramposition(PCF2119_DISPLAY_START_POSITION);
    display.printf("Noch %ds", i);

    delay(1000);
  }

  display.clear_screen();
  display.return_home();
  display.set_ramposition(PCF2119_DISPLAY_START_POSITION);
  display.printf("Go");

  delay(500);

  display.clear_screen();                                     // Anzeigen des Spielernamens auf dem Display
  display.return_home();
  display.set_ramposition(PCF2119_DISPLAY_START_POSITION);
  display.printf("%-10s Lives: %d", x.name1.c_str(), Leben);

  ITimer0.attachInterruptInterval(60000000, TimerHandler0);   // Aktiviere Timer0, zuständig für die Dauer des Spiels

  if(x.Modus == 2)
  {
    while((success2 == false)||(beacon % 10 != 0)||((beacon/10) != x.Teamfarbe[x.num]))
    {
      delay(100);
      if(dauer >= x.Laenge) break;
    }
    success2 = false;
    beacon = 0;
  }

  LED(x.Teamfarbe[x.num]);                                    // Team-LED ein 
  
  attachInterrupt(Receiver_Pin, ISR, CHANGE);
}

void loop()
{ 
  if(dauer < x.Laenge)                      // Dauer des Spieles wird geprüft
  {
    if(((ID[1]-ID[0]) > 900)&&((ID[1]-ID[0]) < 1100)&&((ID[2]-ID[1]) > 400)&&((ID[2]-ID[1]) < 600)&&((ID[21]-ID[20]) > 400)&&((ID[21]-ID[20]) < 600))       // Validieren des Start- und Stop-Bits
    {
      bool stat[9];
      for (int i = 2; i < 19; i+=2)        // Decodieren
      {
         if(((ID[i+1]-ID[i]) > 400)&&((ID[i+1]-ID[i]) < 600)&&((ID[i+2]-ID[i+1]) > 400)&&((ID[i+2]-ID[i+1]) < 600)) stat[i/2-1] = false;
         else if(((ID[i+1]-ID[i]) > 600)&&((ID[i+1]-ID[i]) < 800)&&((ID[i+2]-ID[i+1]) > 200)&&((ID[i+2]-ID[i+1]) < 400)) stat[i/2-1] = true;
      }
      if(stat[0]&&stat[1]&&stat[2]&&stat[3]&&stat[4]&&stat[5]&&stat[6]&&stat[7]&&stat[8]&&x.name10!="")
      {
        if((x.Teamfarbe[9] == x.Teamfarbe[x.num])&&x.Aktiv_Friendlyfire&&(x.Modus != 2)) Hit(9);
        else if(x.Teamfarbe[9] != x.Teamfarbe[x.num]) Hit(9);
      }
      else if(stat[0]&&stat[1]&&stat[2]&&stat[3]&&stat[4]&&stat[5]&&stat[6]&&stat[7]&&!stat[8]&&x.name9!="")
      {
        if((x.Teamfarbe[8] == x.Teamfarbe[x.num])&&x.Aktiv_Friendlyfire&&(x.Modus != 2)) Hit(8);
        else if(x.Teamfarbe[8] != x.Teamfarbe[x.num]) Hit(8);
      }
      else if(stat[0]&&stat[1]&&stat[2]&&stat[3]&&stat[4]&&stat[5]&&stat[6]&&!stat[7]&&!stat[8]&&x.name8!="")
      {
        if((x.Teamfarbe[7] == x.Teamfarbe[x.num])&&x.Aktiv_Friendlyfire&&(x.Modus != 2)) Hit(7);
        else if(x.Teamfarbe[7] != x.Teamfarbe[x.num]) Hit(7);
      }
      else if(stat[0]&&stat[1]&&stat[2]&&stat[3]&&stat[4]&&stat[5]&&!stat[6]&&!stat[7]&&!stat[8]&&x.name7!="")
      {
        if((x.Teamfarbe[6] == x.Teamfarbe[x.num])&&x.Aktiv_Friendlyfire&&(x.Modus != 2)) Hit(6);
        else if(x.Teamfarbe[6] != x.Teamfarbe[x.num]) Hit(6);
      }
      else if(stat[0]&&stat[1]&&stat[2]&&stat[3]&&stat[4]&&!stat[5]&&!stat[6]&&!stat[7]&&!stat[8]&&x.name6!="")
      {
        if((x.Teamfarbe[5] == x.Teamfarbe[x.num])&&x.Aktiv_Friendlyfire&&(x.Modus != 2)) Hit(5);
        else if(x.Teamfarbe[5] != x.Teamfarbe[x.num]) Hit(5);
      }
      else if(stat[0]&&stat[1]&&stat[2]&&stat[3]&&!stat[4]&&!stat[5]&&!stat[6]&&!stat[7]&&!stat[8]&&x.name5!="")
      {
        if((x.Teamfarbe[4] == x.Teamfarbe[x.num])&&x.Aktiv_Friendlyfire&&(x.Modus != 2)) Hit(4);
        else if(x.Teamfarbe[4] != x.Teamfarbe[x.num]) Hit(4);
      }
      else if(stat[0]&&stat[1]&&stat[2]&&!stat[3]&&!stat[4]&&!stat[5]&&!stat[6]&&!stat[7]&&!stat[8]&&x.name4!="")
      {
        if((x.Teamfarbe[3] == x.Teamfarbe[x.num])&&x.Aktiv_Friendlyfire&&(x.Modus != 2)) Hit(3);
        else if(x.Teamfarbe[3] != x.Teamfarbe[x.num]) Hit(3);
      }
      else if(stat[0]&&stat[1]&&!stat[2]&&!stat[3]&&!stat[4]&&!stat[5]&&!stat[6]&&!stat[7]&&!stat[8]&&x.name3!="")
      {
        if((x.Teamfarbe[2] == x.Teamfarbe[x.num])&&x.Aktiv_Friendlyfire&&(x.Modus != 2)) Hit(2);
        else if(x.Teamfarbe[2] != x.Teamfarbe[x.num]) Hit(2);
      }
      else if(stat[0]&&!stat[1]&&!stat[2]&&!stat[3]&&!stat[4]&&!stat[5]&&!stat[6]&&!stat[7]&&!stat[8]&&x.name2!="")
      {
        if((x.Teamfarbe[1] == x.Teamfarbe[x.num])&&x.Aktiv_Friendlyfire&&(x.Modus != 2)) Hit(1);
        else if(x.Teamfarbe[1] != x.Teamfarbe[x.num]) Hit(1);
      }
    }
    attachInterrupt(Receiver_Pin, ISR, CHANGE);
    if((micros()-ID[0]) > 12000)          // Reset unvollständige Daten bei Timeout
    {
      for (int i = 0; i < 22; i++)      // Reset IR-Empfangsbuffer
      {
        ID[i] = 0;
      }
      count = 0;
    }
    if(change)
    {
      change = false;
      display.clear_screen();
      display.return_home();
      display.set_ramposition(PCF2119_DISPLAY_START_POSITION);
      display.printf("%-10s Lives: %d", x.name1.c_str(), Leben);
    }
    if(success2&&(beacon != x.Teamfarbe[x.num])&&(beacon > 0)&&(beacon < 7)&&(x.Modus == 2))
    {
      x.Deaths[x.num]++;
      success2 = false;
      beacon = 0;
    }
    if(Magazin > 0)                         // Schuss nur wenn noch Munition im Magazin ist
    {
      if(x.Full_Auto)                       // Schnellfeuer
      {
        if(digitalRead(Trigger_Pin) == HIGH) Shoot();
      }
      else
      {
        Status_alt = Status;
        Status = digitalRead(Trigger_Pin);
        if((Status == HIGH)&&(Status_alt == LOW))
        {
          delay(1);
          if(digitalRead(Trigger_Pin) == HIGH) Shoot();
        }
      } 
    }
    else
    {
      Status_alt = Status;
      Status = digitalRead(Trigger_Pin);
      if((Status == HIGH)&&(Status_alt == LOW))
      {
        delay(1);
        if(digitalRead(Trigger_Pin) == HIGH)
        {
          while(DataIdx<=WavHeader4.DataSize)
          {
            size_t BytesWritten;                            
            i2s_write(i2s_num,TheData4+DataIdx,4,&BytesWritten,portMAX_DELAY); 
            DataIdx+=4;
          }
          DataIdx=0;
        }
      }
    }

// Magazin-Reload \\

    if((digitalRead(Menue_Pin) == HIGH)&&(reload == -1)&&x.Aktiv_Magazin)
    {
      reload = 0;
      ITimer1.attachInterruptInterval(1000000, TimerHandler1);
    }
    else if(reload == 5)
    {
      ITimer1.stopTimer();
      Magazin = x.Magazin_Reload;
      reload = -1;
      while(DataIdx<=WavHeader5.DataSize)
      {
        size_t BytesWritten;                            
        i2s_write(i2s_num,TheData5+DataIdx,4,&BytesWritten,portMAX_DELAY); 
        DataIdx+=4;
      }
      DataIdx=0;
      LED(x.Teamfarbe[x.num]);
    }
    else if((reload == 4)||(reload == 2))					// Team-LED blinkt solang nachgeladen wird
    {
      LED(x.Teamfarbe[x.num]);
    }
    else if((reload == 3)||(reload == 1))
    {
      LED(0);
    }
    if(digitalRead(Menue_Pin) == HIGH)
    {
      druck++;
      delay(10);
    }
    else druck = 0;
    if(druck == 500) digitalWrite(Enable_Pin, LOW);
  }
  else
  {
    display.clear_screen();
    display.return_home();
    display.set_ramposition(PCF2119_DISPLAY_START_POSITION);
    display.printf("Game Over!");

    LED(0);                                                               // Team-LED aus

    ITimer0.stopTimer();
    detachInterrupt(Receiver_Pin);

    delay(2000);

    esp_now_send(mac0, (uint8_t *) &x, sizeof(x));                        // Senden an Server
    int i = 0;
    while((success1 == false)&&(i < 600))                                 // Versuche erneut zu senden
    {
      delay(1000);
      i++;
      esp_now_send(mac0, (uint8_t *) &x, sizeof(x));
    }
  
    digitalWrite(Enable_Pin, LOW);                                        // Waffe aus
  }                              
}

void LED(uint8_t i)
{
  if(i == 0)                      //Aus
  {
    digitalWrite(R_Led_Pin, LOW);
    digitalWrite(G_Led_Pin, LOW);
    digitalWrite(B_Led_Pin, LOW);
  }
  else if(i == 1)                 //Rot
  {
    digitalWrite(R_Led_Pin, HIGH);
    digitalWrite(G_Led_Pin, LOW);
    digitalWrite(B_Led_Pin, LOW);
  }
  else if(i == 2)                 //Grün
  {
    digitalWrite(R_Led_Pin, LOW);
    digitalWrite(G_Led_Pin, HIGH);
    digitalWrite(B_Led_Pin, LOW);
  }
  else if(i == 3)                 //Blau
  {
    digitalWrite(R_Led_Pin, LOW);
    digitalWrite(G_Led_Pin, LOW);
    digitalWrite(B_Led_Pin, HIGH);
  }
  else if(i == 4)                 //Gelb
  {
    digitalWrite(R_Led_Pin, HIGH);
    digitalWrite(G_Led_Pin, HIGH);
    digitalWrite(B_Led_Pin, LOW);
  }
  else if(i == 5)                 //Cyan
  {
    digitalWrite(R_Led_Pin, LOW);
    digitalWrite(G_Led_Pin, HIGH);
    digitalWrite(B_Led_Pin, HIGH);
  }
  else if(i == 6)                 //Magenta
  {
    digitalWrite(R_Led_Pin, HIGH);
    digitalWrite(G_Led_Pin, LOW);
    digitalWrite(B_Led_Pin, HIGH);
  }
  else if(i == 7)                 //Weiß
  {
    digitalWrite(R_Led_Pin, HIGH);
    digitalWrite(G_Led_Pin, HIGH);
    digitalWrite(B_Led_Pin, HIGH);
  }
}

void Shoot()
{
  digitalWrite(Laser_Pin, HIGH);    // Laser ein
  ledcWrite(0, 127);
  delayMicroseconds(1000);
  ledcWrite(0, 0);
  delayMicroseconds(500);
  
  for (int i = 0; i < 10; i++)
  {
    if(i < x.num)
    {
      ledcWrite(0, 127);
      delayMicroseconds(700);
      ledcWrite(0, 0);
      delayMicroseconds(300);
    }
    else
    {
      ledcWrite(0, 127);
      delayMicroseconds(500);
      ledcWrite(0, 0);
      delayMicroseconds(500);
    }
  }
  digitalWrite(Laser_Pin, LOW);     // Laser aus

  for (int i = 0; i < 22; i++)      // Reset IR-Empfangsbuffer
  {
    ID[i] = 0;
  }
  count = 0;
  
  if(x.Full_Auto)                   // Sound für Schnellfeuer
  {
    while(DataIdx<=WavHeader2.DataSize)
    {
      size_t BytesWritten;                            
      i2s_write(i2s_num,TheData2+DataIdx,4,&BytesWritten,portMAX_DELAY); 
      DataIdx+=4;
    }
    delay(120);
    DataIdx=0;
  }
  else                              // Sound für normalen Schuss
  {
    while(DataIdx<=WavHeader1.DataSize)
    {
      size_t BytesWritten;                            
      i2s_write(i2s_num,TheData1+DataIdx,4,&BytesWritten,portMAX_DELAY); 
      DataIdx+=4;       
    }
    DataIdx=0;
  }
  if(x.Aktiv_Magazin) Magazin--;    // Magazin um eins reduzieren
  x.Schuss++;                       // Schuss-Zähler um eins erhöhen
}
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

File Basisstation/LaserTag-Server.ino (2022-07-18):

#include <esp_now.h>
#include <WiFi.h>
#include <AsyncTCP.h>
#include <ESPAsyncWebServer.h>

#define Start_Pin 1
#define Config_Pin 2
#define Spiel_Pin 3
#define Ergebnis_Pin 4

AsyncWebServer server(80);                        // Initialisierung des Webserver auf Port 80   

struct Daten                                      // Datenpaket für jeden Spieler
{  
  uint8_t num;                                    // Dient der Identifikation

  uint8_t Magazin_Reload = 9;                     // Nachlade-Wert für das Magazin
  uint8_t Modus;                                  // Spielmodus 0: Standard, 1: Battle Royal, 2: Capture the Flag
  bool Aktiv_Magazin;				                      // Magazin-Feature Aktivierung
  bool Full_Auto;                                 // Schnellfeuer Aktivierung
  uint8_t Laenge;                                 // Dauer des Spiels in Minuten
  uint8_t Leben_Reload = 5;                       // Leben für Battle Royal Spielmodus
  short Reload_Zeit = 60;                         // Respawn-Zeit für Battle Royal Spielmodus
  short Spawn_Zeit = 12;                          // Respawn-Zeit allgemein

  uint8_t Teamfarbe[10];                              // 0 = Aus, 1 = Rot, 2 = Grün, 3 = Blau, 4 = Gelb, 5 = Cyan, 6 = Magent, 7 = Weiß
  short Schuss = 0;                                   // Anzahl der abgegebenen Schüsse
  uint8_t Deaths[10] = {0,0,0,0,0,0,0,0,0,0};         // Anzahl der erhaltenen Treffer pro Spieler
  String name1 = "";                                  // Namen aller Spieler, max. 10 Zeichen
  String name2 = "";
  String name3 = "";
  String name4 = "";
  String name5 = "";
  String name6 = "";
  String name7 = "";
  String name8 = "";
  String name9 = "";
  String name10 = "";
};

int Spieler_Anzahl;                                 // Anzahl der Spieler im Spiel
Daten x,y;                                          // Spieldaten
int d = 0;
short schuss[10];
uint8_t deaths[10][10];
bool pakete[10] = {false, false, false, false, false, false, false, false, false, false};          // Anzahl der bisher empfangenen Pakete
uint8_t mac[] = {0xFF, 0xFF, 0xFF, 0xFF, 0xFF, 0xFF};   // MAC-Adresse Broadcast

  // Parameter um Daten aus html1 zu bekommen

const char* input_parameter1 = "input1";
const char* input_parameter2 = "input2";
const char* input_parameter3 = "input3";
const char* input_parameter4 = "input4";
const char* input_parameter5 = "input5";
const char* input_parameter6 = "input6_1";
const char* input_parameter7 = "input6_2";
const char* input_parameter8 = "input7_1";
const char* input_parameter9 = "input7_2";
const char* input_parameter10 = "input8_1";
const char* input_parameter11 = "input8_2";
const char* input_parameter12 = "input9_1";
const char* input_parameter13 = "input9_2";
const char* input_parameter14 = "input10_1";
const char* input_parameter15 = "input10_2";
const char* input_parameter16 = "input11_1";
const char* input_parameter17 = "input11_2";
const char* input_parameter18 = "input12_1";
const char* input_parameter19 = "input12_2";
const char* input_parameter20 = "input13_1";
const char* input_parameter21 = "input13_2";
const char* input_parameter22 = "input14_1";
const char* input_parameter23 = "input14_2";
const char* input_parameter24 = "input15_1";
const char* input_parameter25 = "input15_2";

  // Konfiguration-Website \\

const char html1[] PROGMEM = R"rawliteral(
<!DOCTYPE html><html><head>
<title>Konfiguration</title>
<meta http-equiv="content-type" content="text/html; charset=utf-8"></head>
<body>
<h1>Spiel-Starter</h1>
<h3>Einstellen der Spiel-Parameter</h3>
<form action="/get">
  <label for="num">Anzahl der Spieler:</label>
  <select id="num" name="input1">
    <option value="2">2</option>
    <option value="3">3</option>
    <option value="4">4</option>
    <option value="5">5</option>
    <option value="6">6</option>
    <option value="7">7</option>
    <option value="8">8</option>
    <option value="9">9</option>
    <option value="10">10</option>
  </select><br>
  <label for="mode">Spielmodus:</label>
  <select id="mode" name="input2">
    <option value="0">Standard</option>
    <option value="1">Battle Royal</option>
    <option value="2">Capture the Flag</option>
  </select><br>
  <label for="dauer">Dauer des Spiels in Minuten (1-60):</label>
  <input type="number" id="dauer" name="input3" min="1" max="60"><br>
  <label for="mag">Aktivierung des Magazins:</label>
  <select id="mag" name="input4">
    <option value="1">Ja</option>
    <option value="0">Nein</option>
  </select><br>
  <label for="full">Schnellfeuer-Modus:</label>
  <select id="full" name="input5">
    <option value="1">Ja</option>
    <option value="0">Nein</option>
  </select><hr>
<h3>Team-Konfiguration</h3>
<label for="name1">Name für Spieler1:</label>
  <input type="text" id="name1" name="input6_1" maxlength="10">
<label for="team1">Team-Farbe:</label>
  <select id="team1" name="input6_2">
    <option value="0">-</option>
    <option value="1">Rot</option>
    <option value="2">Grün</option>
    <option value="3">Blau</option>
    <option value="4">Gelb</option>
    <option value="5">Cyan</option>
    <option value="6">Magenta</option>
  </select><br>
<label for="name2">Name für Spieler2:</label>
  <input type="text" id="name2" name="input7_1" maxlength="10">
<label for="team2">Team-Farbe:</label>
  <select id="team2" name="input7_2">
    <option value="0">-</option>
    <option value="1">Rot</option>
    <option value="2">Grün</option>
    <option value="3">Blau</option>
    <option value="4">Gelb</option>
    <option value="5">Cyan</option>
    <option value="6">Magenta</option>
  </select><br>
<label for="name3">Name für Spieler3:</label>
  <input type="text" id="name3" name="input8_1" maxlength="10">
<label for="team3">Team-Farbe:</label>
  <select id="team3" name="input8_2">
    <option value="0">-</option>
    <option value="1">Rot</option>
    <option value="2">Grün</option>
    <option value="3">Blau</option>
    <option value="4">Gelb</option>
    <option value="5">Cyan</option>
    <option value="6">Magenta</option>
  </select><br>
<label for="name4">Name für Spieler4:</label>
  <input type="text" id="name4" name="input9_1" maxlength="10">
<label for="team4">Team-Farbe:</label>
  <select id="team4" name="input9_2">
    <option value="0">-</option>
    <option value="1">Rot</option>
    <option value="2">Grün</option>
    <option value="3">Blau</option>
    <option value="4">Gelb</option>
    <option value="5">Cyan</option>
    <option value="6">Magenta</option>
  </select><br>
<label for="name5">Name für Spieler5:</label>
  <input type="text" id="name5" name="input10_1" maxlength="10">
<label for="team5">Team-Farbe:</label>
  <select id="team5" name="input10_2">
    <option value="0">-</option>
    <option value="1">Rot</option>
    <option value="2">Grün</option>
    <option value="3">Blau</option>
    <option value="4">Gelb</option>
    <option value="5">Cyan</option>
    <option value="6">Magenta</option>
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
